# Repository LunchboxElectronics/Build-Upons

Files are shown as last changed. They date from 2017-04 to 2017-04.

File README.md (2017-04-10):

# Build-Upons
Build Upons v1
About:  
- Build Upons is a construction block set that is designed to be compatible with most popular 
construction block sets like LEGO bricks. The set allows for the seamless integration of LED 
light into an existing construction set, or Build Upons can be used to create truly unique 
creations with only the three simple block provided. The Power brick, the Bridge brick, and 
the LED brick. This repo provides the 3D solid models and their respective 2D drawings. 

Processes:
There are two different processes used in the creation of Build Upons

 - Die Casting:
	Each brick contains a pair of zinc die casted parts that serve as the electrical connection between the bricks.
	The repo contains the 3D model and 2D drawings used to create the detail for the core and cavity of the die cast tool.
	A die cast tool has been created with 16 cavities for the Power brick A and B, Bridge brick, and LED brick parts.
	
 - Injection Molding:
	Each brick is then molded in plastic to create the compatible form for existing construction sets. In the case of Build Upons
	the bricks use a process called insert molding to encapsulate the die cast parts into the plastic.
	The repo contains the 3D model and 2D drawings to create the detail for the core and cavity of the insert mold tool.
	An insert mold tool has been created with a single cavity for the Power brick, Bridge brick, and LED brick.

Licensing: 
Build Upons is an open source hardware product and follows the open source hardware definition: www.oshwa.org/definition
The license on the source files for Build Upons is CC-BY-SA

Distributed as-is; no warranty given. Not suitable for people who might eat electronics.

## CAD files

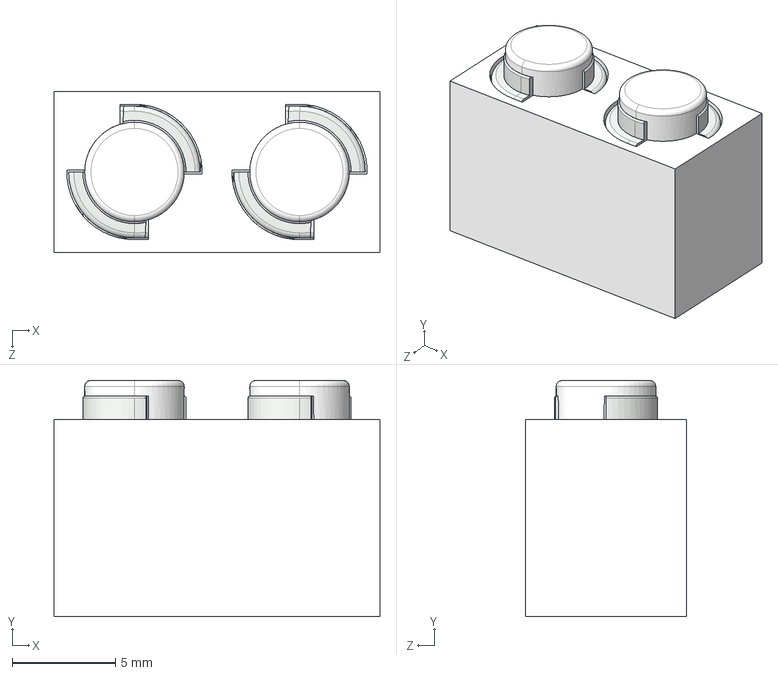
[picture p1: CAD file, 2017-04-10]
Complete Assemblies/BuildUponsBridgeBrickCompleteV3.STEP
15.8 x 11.5 x 7.80 mm
BuildUponsBridgeBrickV3_3
BuildUponsBridgeMetalV3 x 2

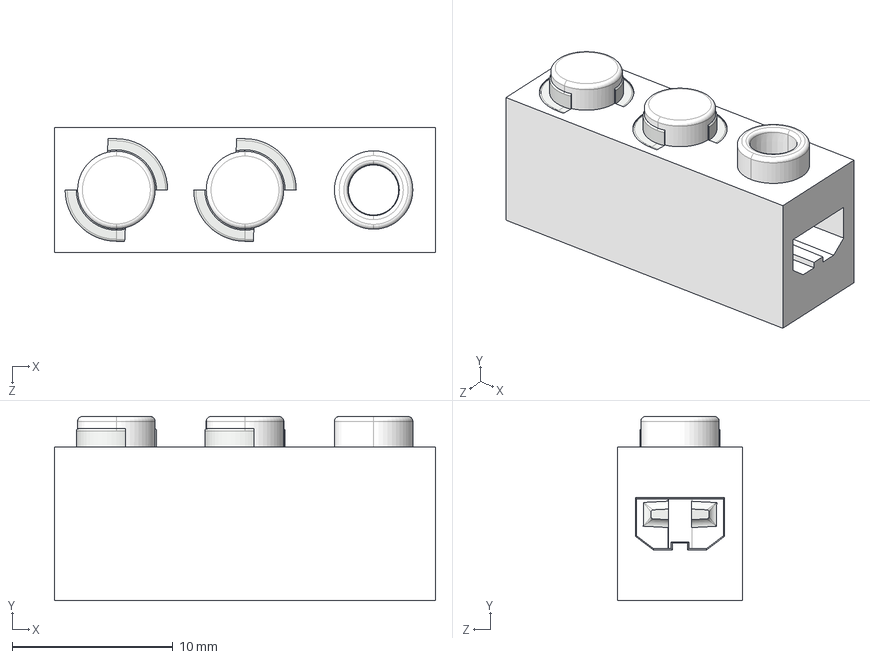
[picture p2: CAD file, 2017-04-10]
Complete Assemblies/BuildUponsPowerBrickCompleteV3.STEP
23.7 x 11.4 x 7.80 mm
BuildUponsPowerBrickV2
PowerBrickMetalSideAV4
PowerBrickMetalSideBV4

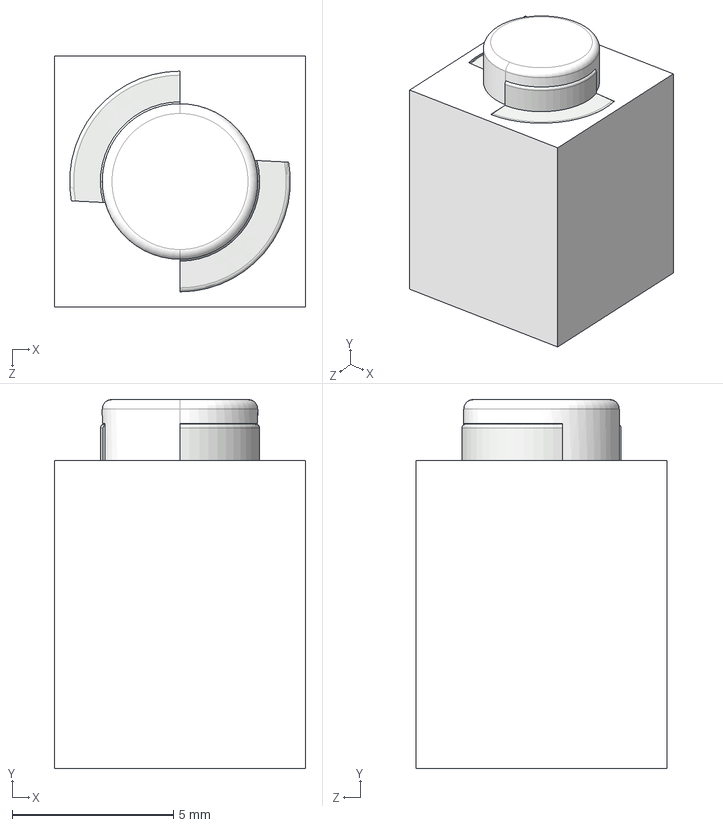
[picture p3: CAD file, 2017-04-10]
Complete Assemblies/BuildUponsLEDBrickCompleteV4.STEP
7.80 x 11.4 x 7.80 mm
LEDBodyV4
BuildUponsLEDBrickMetalV3 x 2
LEDBrickSpacer
Build Upons LED Brick PCB
PLCC4 LED
0603 Resistor

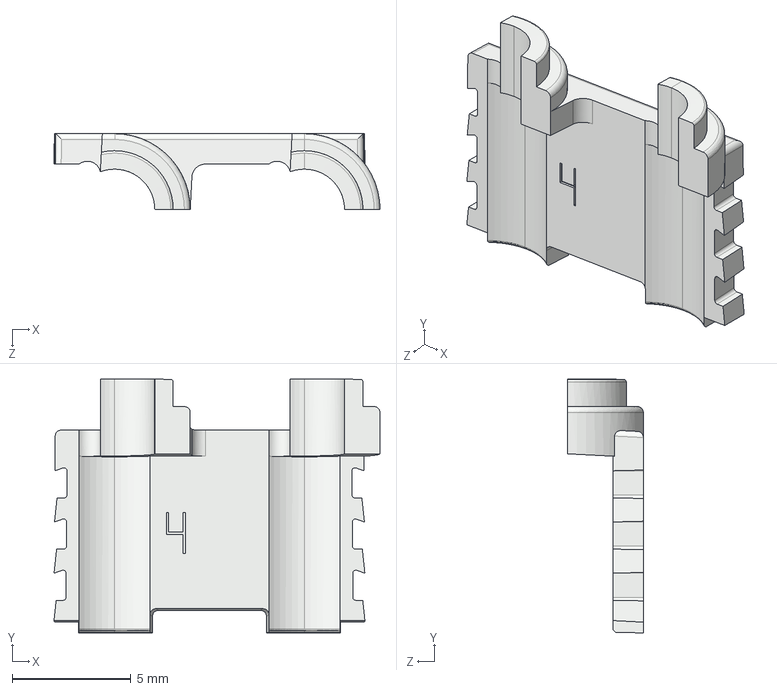
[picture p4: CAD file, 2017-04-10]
Die Casted Parts/Bridge Brick/BuildUponsBridgeMetalV3R2.STEP
13.7 x 10.7 x 3.19 mm

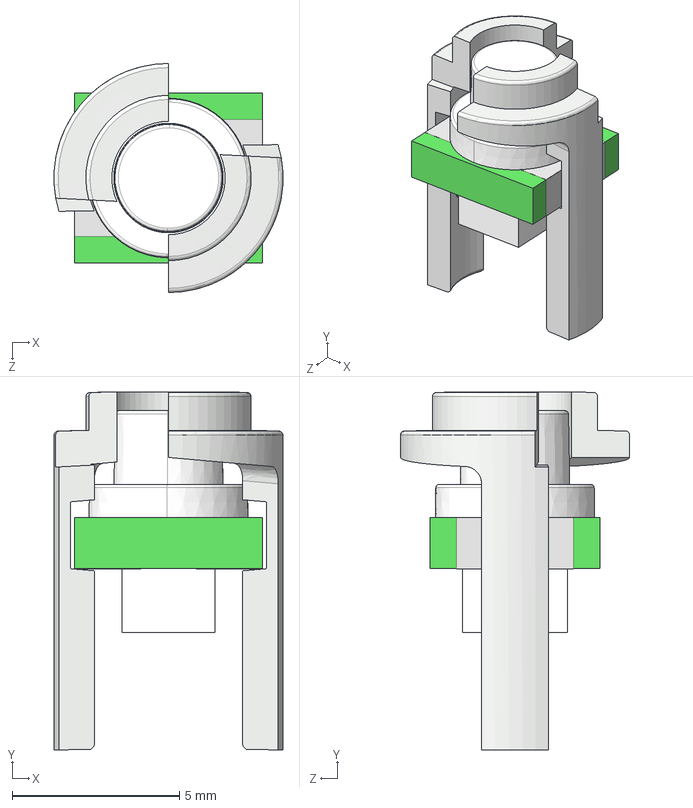
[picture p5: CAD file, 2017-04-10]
Die Casted Parts/LED Brick/BuildUponsLEDAssemV2.STEP
6.84 x 10.7 x 6.85 mm
BuildUponsLEDBrickMetalV3 x 2
LEDBrickSpacer
Build Upons LED Brick PCB
PLCC4 LED
0603 Resistor

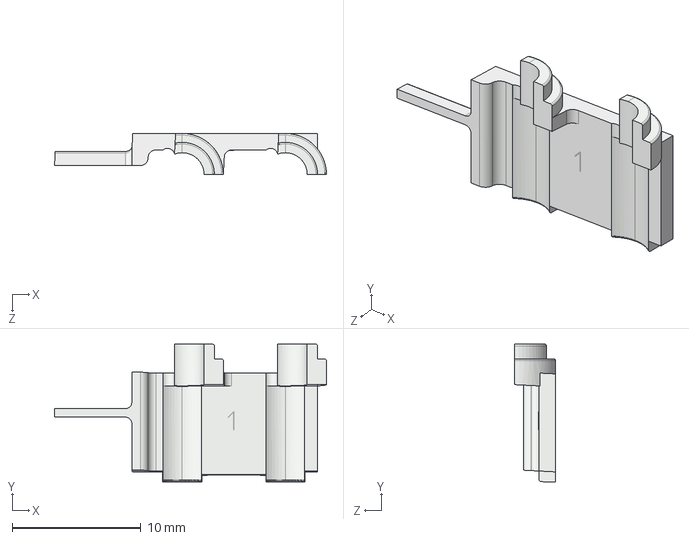
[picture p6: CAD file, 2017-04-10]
Die Casted Parts/Power Brick/PowerBrickMetalSideAV4.STEP
21.1 x 10.7 x 3.19 mm

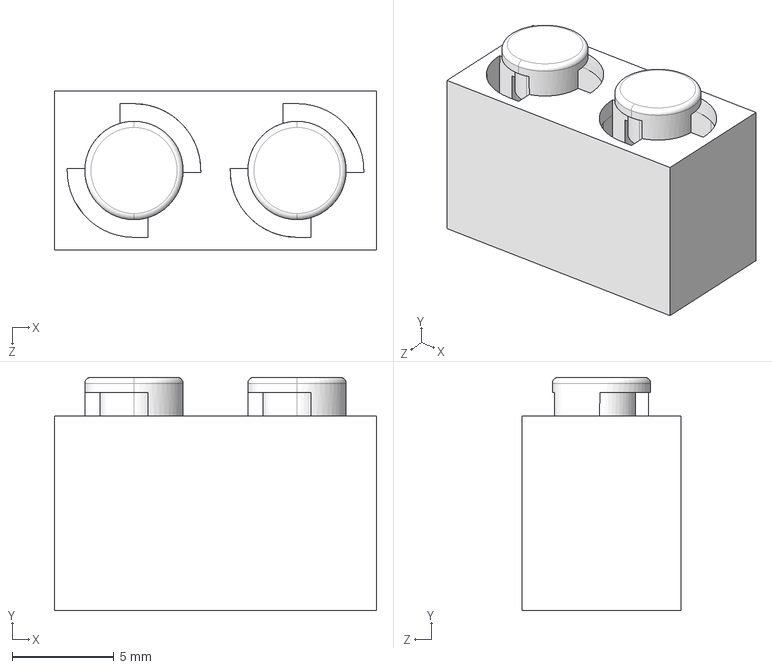
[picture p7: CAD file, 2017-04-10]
Plastic Molded Parts/Bridge Brick/BuildUponsBridgeBrickV3R3.STEP
15.8 x 11.5 x 7.80 mm

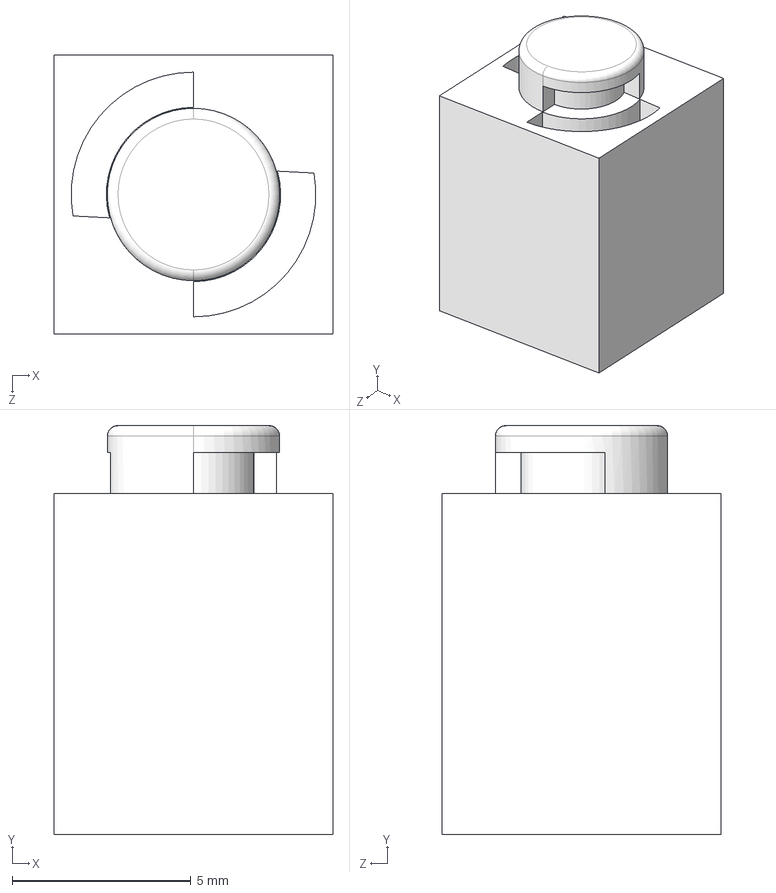
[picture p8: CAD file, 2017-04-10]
Plastic Molded Parts/LED Brick/LEDBodyV4.STEP
7.80 x 11.4 x 7.80 mm

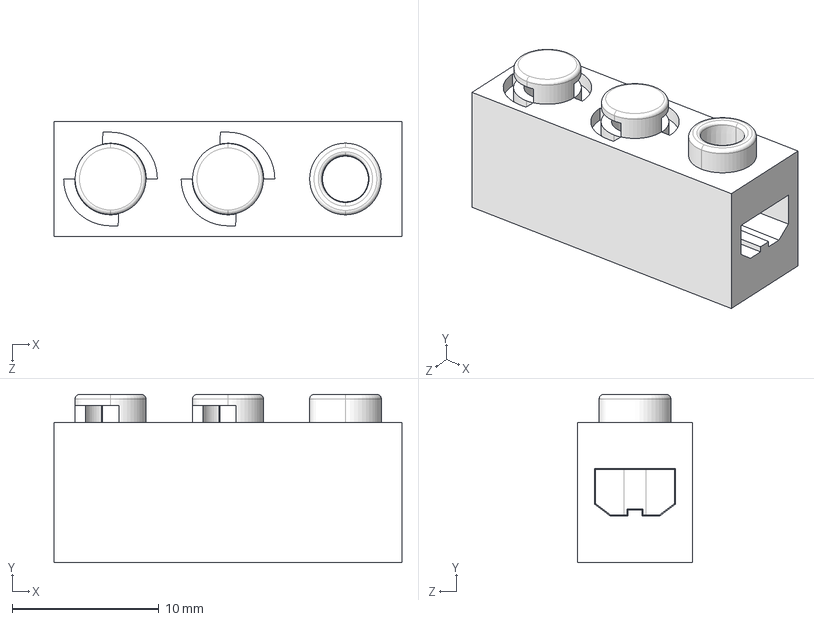
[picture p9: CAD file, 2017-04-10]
Plastic Molded Parts/Power Brick/BuildUponsPowerBrickV2.STEP
23.7 x 11.4 x 7.80 mm

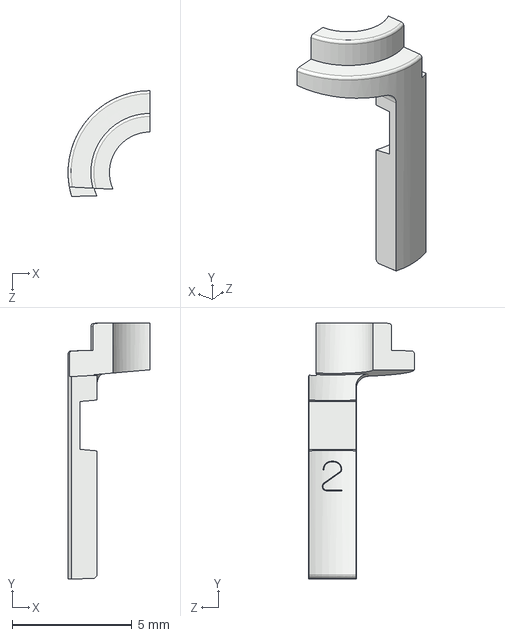
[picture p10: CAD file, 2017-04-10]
Die Casted Parts/LED Brick/BuildUponsLEDBrickMetalV3.STEP
3.42 x 10.7 x 4.42 mm

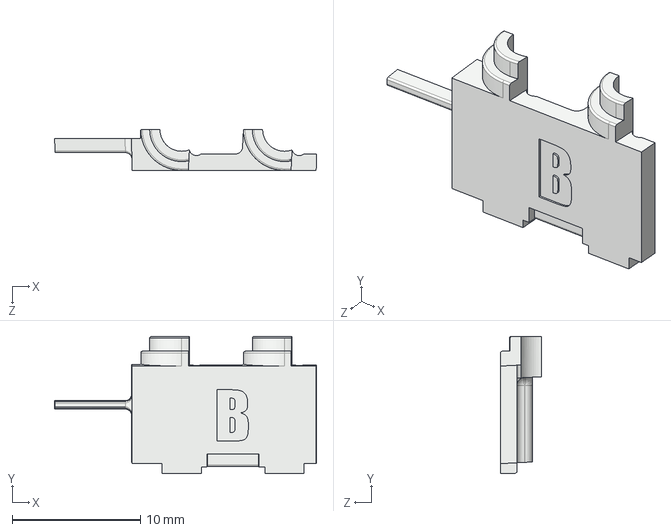
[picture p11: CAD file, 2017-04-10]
Die Casted Parts/Power Brick/PowerBrickMetalSideBV4.STEP
20.4 x 10.7 x 3.19 mm

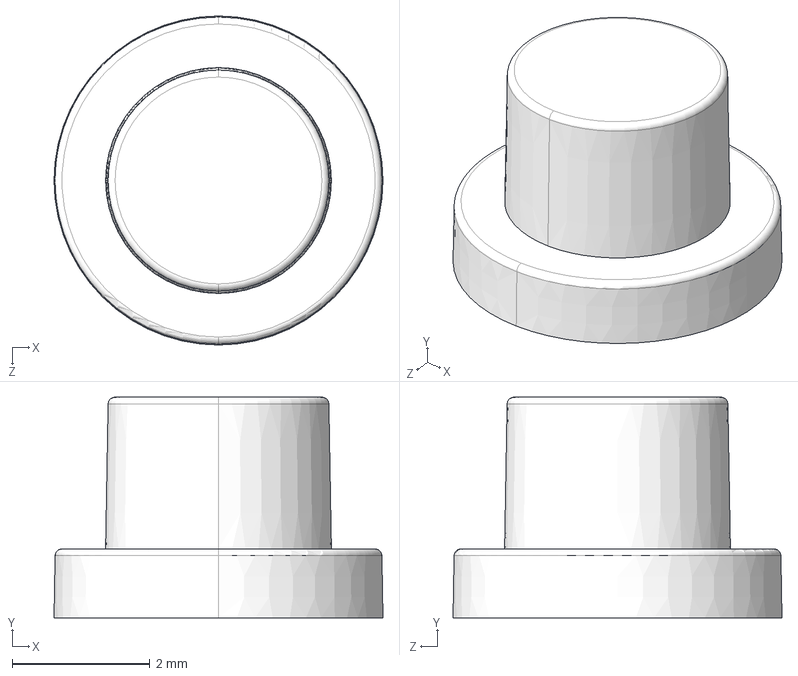
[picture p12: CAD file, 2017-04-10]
Plastic Molded Parts/LED Brick/LEDBrickSpacer.STEP
4.77 x 3.20 x 4.77 mm

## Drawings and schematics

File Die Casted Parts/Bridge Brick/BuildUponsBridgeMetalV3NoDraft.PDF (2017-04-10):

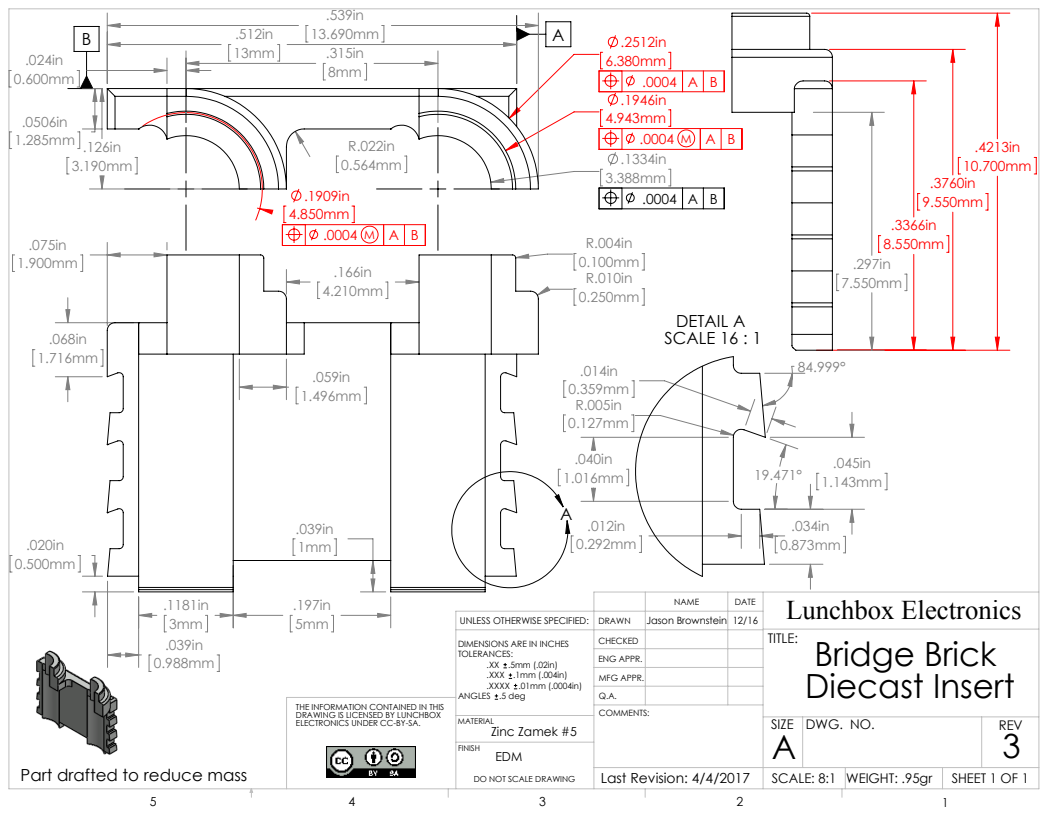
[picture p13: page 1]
DETAIL A SCALE 16 : 1; Bridge Brick Diecast Insert; SHEET 1 OF 1; UNLESS OTHERWISE SPECIFIED:; Jason Brownstein 12/16; SCALE: 8:1 WEIGHT: .95gr; DWG. NO.; REV; Lunchbox Electronics NAME; DATE; MFG APPR.; ENG APPR.; Last Revision: 4/4/2017

DIMENSIONS ARE IN INCHES
TOLERANCES:
.XXX .1mm (.004in)
.XXXX .01mm (.0004in)
ANGLES .5 deg
Zinc Zamek #5
FINISH
EDM

THE INFORMATION CONTAINED IN THIS
DRAWING IS LICENSED BY LUNCHBOX
ELECTRONICS UNDER CC-BY-SA.

Part drafted to reduce mass

DO NOT SCALE DRAWING

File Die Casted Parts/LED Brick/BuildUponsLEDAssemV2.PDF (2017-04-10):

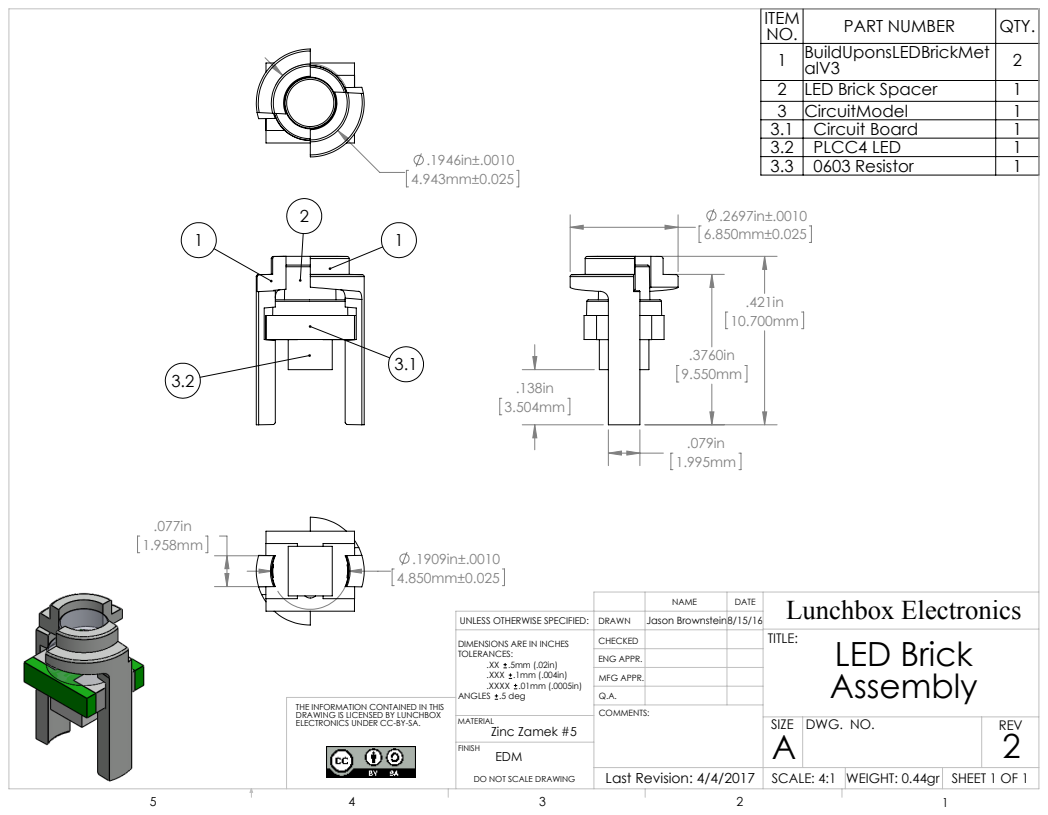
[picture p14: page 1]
LED Brick; SHEET 1 OF 1; UNLESS OTHERWISE SPECIFIED:; Jason Brownstein8/15/16; SCALE: 4:1 WEIGHT: 0.44gr; DWG. NO.; REV; Lunchbox Electronics NAME; DATE; MFG APPR.; ENG APPR.; Last Revision: 4/4/2017

ITEM NO. | PART NUMBER | QTY.
1 | BuildUponsLEDBrickMet alV3 | 2
2 | LED Brick Spacer | 1
3 | CircuitModel | 1
3.1 | Circuit Board | 1
3.2 | PLCC4 LED | 1
3.3 | 0603 Resistor | 1

DIMENSIONS ARE IN INCHES
TOLERANCES:
.XXX .1mm (.004in)
.XXXX .01mm (.0005in)
ANGLES .5 deg
Zinc Zamek #5
FINISH
EDM

THE INFORMATION CONTAINED IN THIS
DRAWING IS LICENSED BY LUNCHBOX
ELECTRONICS UNDER CC-BY-SA.

DO NOT SCALE DRAWING

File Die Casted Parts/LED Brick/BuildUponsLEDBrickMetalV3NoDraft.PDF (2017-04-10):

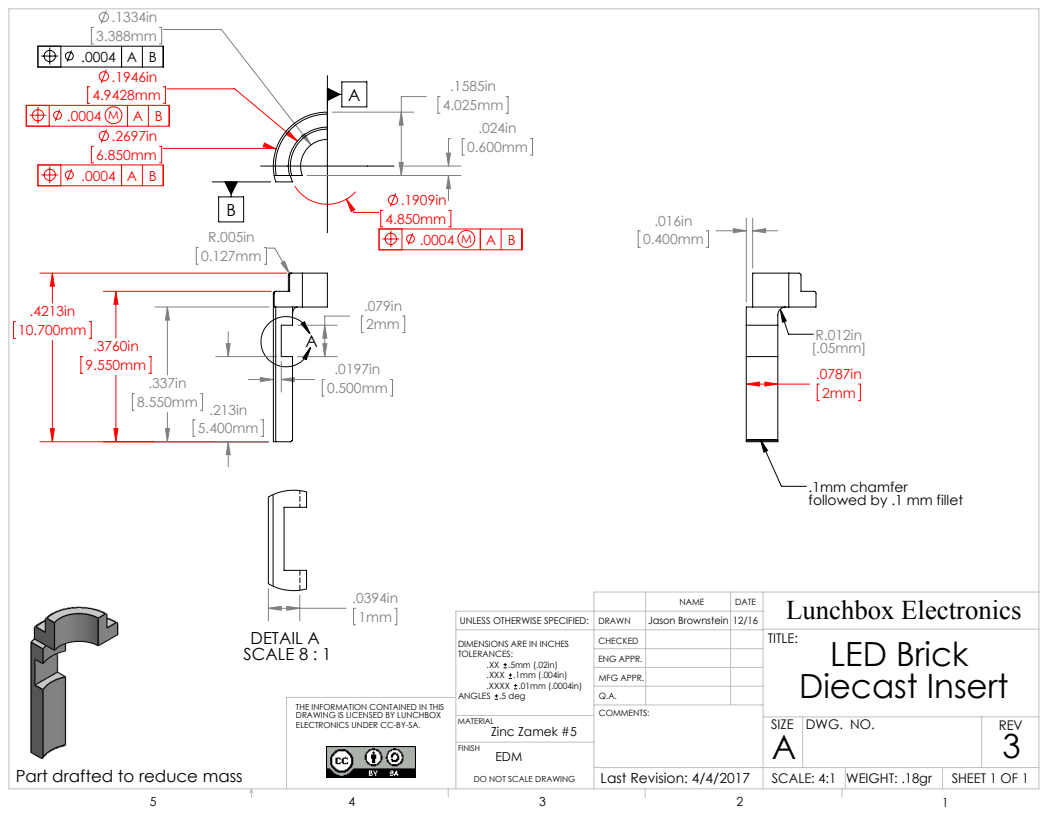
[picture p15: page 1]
DETAIL A SCALE 8 : 1; LED Brick Diecast Insert; SHEET 1 OF 1; UNLESS OTHERWISE SPECIFIED:; Jason Brownstein 12/16; SCALE: 4:1 WEIGHT: .18gr; DWG. NO.; REV; Lunchbox Electronics NAME; DATE; MFG APPR.; ENG APPR.; Last Revision: 4/4/2017

.1mm chamfer
followed by .1 mm fillet

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

THE INFORMATION CONTAINED IN THIS
DRAWING IS LICENSED BY LUNCHBOX
ELECTRONICS UNDER CC-BY-SA.

Part drafted to reduce mass

DO NOT SCALE DRAWING

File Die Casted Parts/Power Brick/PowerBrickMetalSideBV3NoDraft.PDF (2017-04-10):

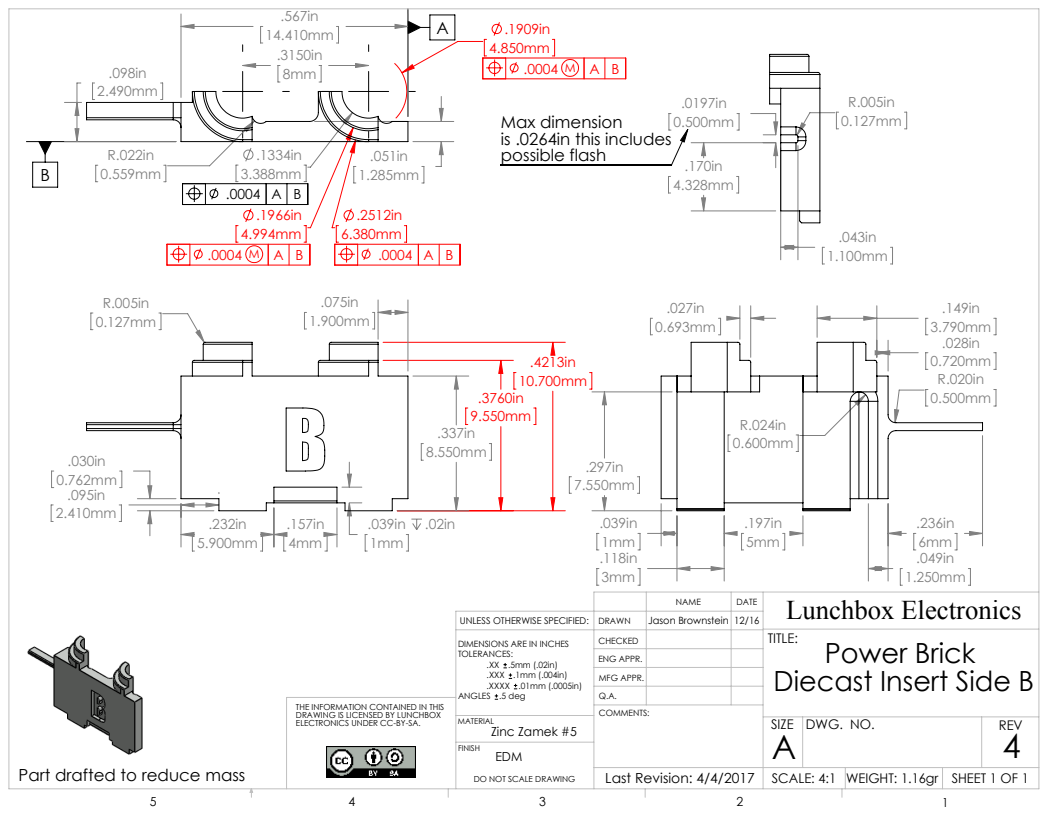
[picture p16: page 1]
Power Brick Diecast Insert Side B; SHEET 1 OF 1; UNLESS OTHERWISE SPECIFIED:; Jason Brownstein 12/16; SCALE: 4:1 WEIGHT: 1.16gr; DWG. NO.; REV; Lunchbox Electronics NAME; DATE; MFG APPR.; ENG APPR.; Last Revision: 4/4/2017

Max dimension
is .0264in this includes
possible flash

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

THE INFORMATION CONTAINED IN THIS
DRAWING IS LICENSED BY LUNCHBOX
ELECTRONICS UNDER CC-BY-SA.

Part drafted to reduce mass

DO NOT SCALE DRAWING

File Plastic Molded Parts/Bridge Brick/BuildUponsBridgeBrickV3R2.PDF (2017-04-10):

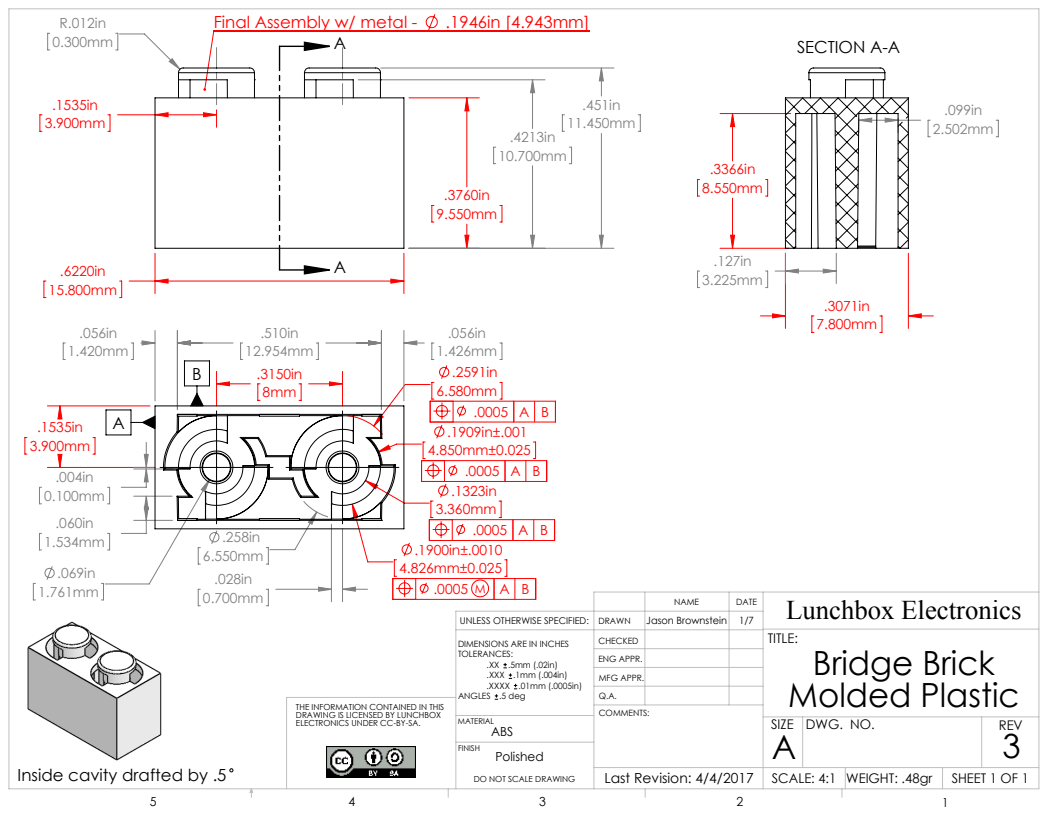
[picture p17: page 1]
Final Assembly w/ metal -; SECTION A-A; Bridge Brick Molded Plastic; SHEET 1 OF 1; UNLESS OTHERWISE SPECIFIED:; Jason Brownstein 1/7; SCALE: 4:1 WEIGHT: .48gr; DWG. NO.; REV; Lunchbox Electronics NAME; DATE; MFG APPR.; ENG APPR.; DIMENSIONS ARE IN INCHES; .XX .5mm (.02in) .XXX .1mm (.004in) .XXXX .01mm (.0005in) ANGLES .5 deg; Last Revision: 4/4/2017

THE INFORMATION CONTAINED IN THIS
DRAWING IS LICENSED BY LUNCHBOX
ELECTRONICS UNDER CC-BY-SA.

Inside cavity drafted by .5

DO NOT SCALE DRAWING

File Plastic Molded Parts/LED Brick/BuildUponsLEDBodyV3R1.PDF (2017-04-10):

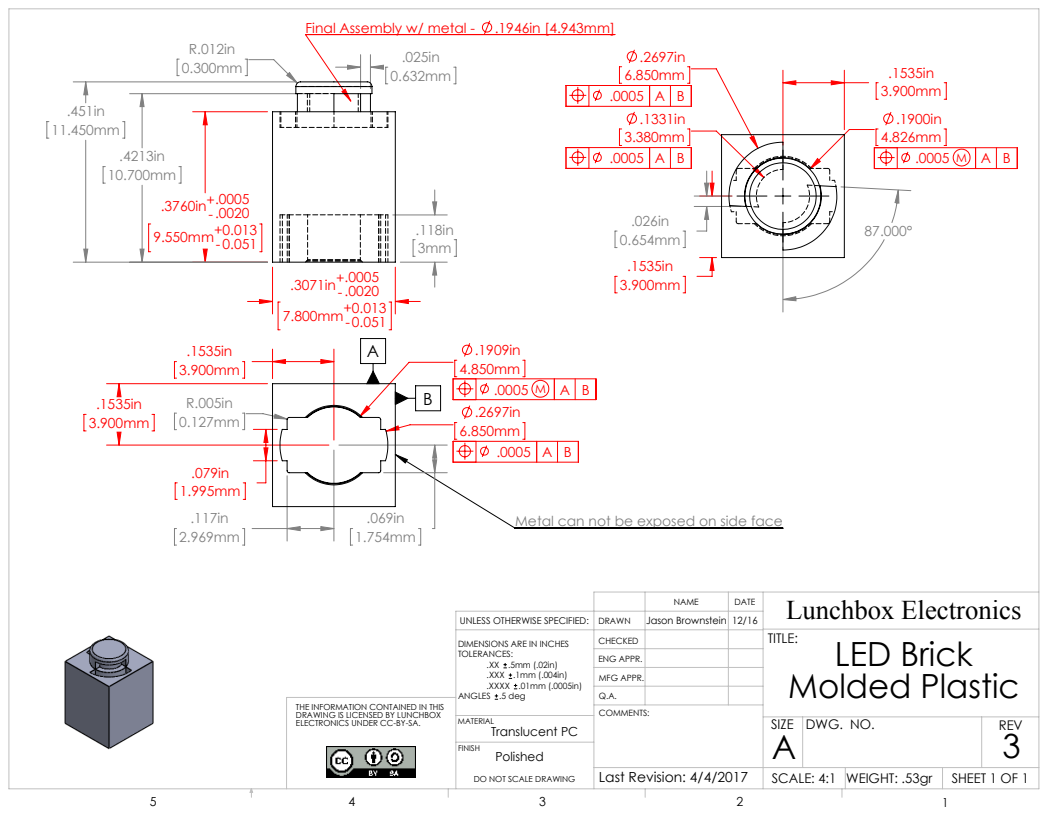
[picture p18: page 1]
LED Brick Molded Plastic; SHEET 1 OF 1; UNLESS OTHERWISE SPECIFIED:; Jason Brownstein 12/16; SCALE: 4:1 WEIGHT: .53gr; DWG. NO.; REV; Lunchbox Electronics NAME; DATE; MFG APPR.; ENG APPR.; Last Revision: 4/4/2017

Final Assembly w/ metal - .1946in [4.943mm]

Metal can not be exposed on side face

DIMENSIONS ARE IN INCHES
TOLERANCES:
.XXX .1mm (.004in)
.XXXX .01mm (.0005in)
ANGLES .5 deg
Translucent PC
FINISH
Polished

THE INFORMATION CONTAINED IN THIS
DRAWING IS LICENSED BY LUNCHBOX
ELECTRONICS UNDER CC-BY-SA.

DO NOT SCALE DRAWING

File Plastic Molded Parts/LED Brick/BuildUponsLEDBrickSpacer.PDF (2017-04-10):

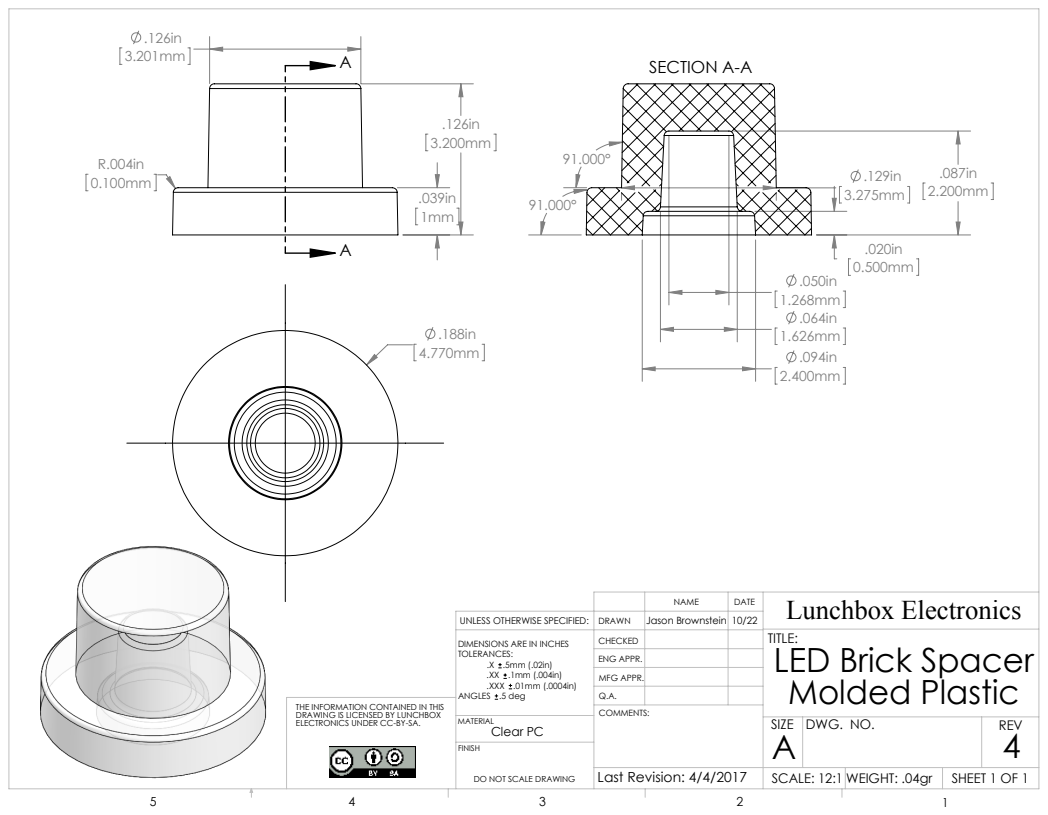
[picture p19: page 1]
SECTION A-A; SHEET 1 OF 1; UNLESS OTHERWISE SPECIFIED:; Jason Brownstein 10/22; SCALE: 12:1 WEIGHT: .04gr; DWG. NO.; REV; Lunchbox Electronics NAME; DATE; MFG APPR.; ENG APPR.; Last Revision: 4/4/2017

LED Brick Spacer
Molded Plastic

DIMENSIONS ARE IN INCHES
TOLERANCES:
.XXX .01mm (.0004in)
ANGLES .5 deg
Clear PC
FINISH

THE INFORMATION CONTAINED IN THIS
DRAWING IS LICENSED BY LUNCHBOX
ELECTRONICS UNDER CC-BY-SA.

DO NOT SCALE DRAWING
